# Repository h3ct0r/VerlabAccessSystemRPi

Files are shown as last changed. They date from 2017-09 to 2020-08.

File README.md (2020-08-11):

# VeRLab Access System - RPi/RFID/Face Recognition

(https://www.verlab.dcc.ufmg.br)

This is the main repo of the Verlab Access System using a Raspberry Pi as main hardware. The authentication is based on RFID or by Face Recognition (beta). List of valid users is updated from an LDAP server and maintained on the device for offline verification.

### Authors
----
- [Hector Azpurua](https://github.com/h3ct0r)
- [Elerson Rubens](https://github.com/elerson)
- [Mauricio Ferrari](https://github.com/mauferrari)

### Why using Rpi instead of Arduino?
----

We love arduino too, but our previous project using Arduino and using the compatible hardware we were able to find in Brazil ended up beign not very reliable. It seems that the ethernet shield is not the most robust piece of hardware out there, and it was a key part for that project.

Using the full power of a Raspberry Pi, it allow us to develop other methods of authentication and/or implement sound, screens, logging and other kind of funcionalities without the 16Kb space limitation. And since all Raspi-berrys are made from the same vendor and quality, we can be certain of the hardware reliability.

### Hardware Information
----
[**Hardware folder**](/hardware) has more information about 3D Printer files, connections, and assembly. 

#### Components List

This access system needs the following parts to work properly:

* *Raspberry Pi* - version 2 or up (We tested Pi2b and 3).
* *RFID Reader* - use the best RFID readers available, we use the **red ones from Funduino** (available fromm MercadoLivre.com.br sellers, look specifically the red ones). The [PN532](https://www.filipeflop.com/produto/kit-modulo-leitor-rfid-nfc-pn532/) is an excellent choice.
* *Door lock* - we used one from HDL ([FEC-91 LA](http://www.hdl.com.br/produtos/fechaduras/fecho-eletrico/fecho-eletrico-mod-fec-91-la-espelho-longo-trinco-ajustavel)).
* *Door lock Power Supply* - we used the HDL's power supply compatible with our door lock ([TRA-400](https://www.hdl.com.br/produtos/fechaduras/acessorios/fonte-tra-400-para-fechaduras-porteiros-e-centrais))
* *Relay switch* - We used common arduino relays.
* *Jumper cables* - a lot of them.
* *Two Patch Painel Female RJ45 Femal* - to leave the pinout to connect the RFID reader and Raspberry pins
* *Ethernet Cable* -  arbitrary size, to connect the RPi to the RFID reader
* Probably, will be necessary other parts for your building infrastructure that are not listed here (e.g. wall mounted plug for power, networking, electric cables, etc)

### Software Installation
----

We rely on Ansible for software installation on the Raspberry. Ansible is a 'automation' tool for configuring servers that we use to simplify the installation process on the door (for a simple guide for Ansible see [Simple Ansible Tutorial](https://serversforhackers.com/c/an-ansible-tutorial)). With this tool is very easy to deploy one or more installations of the Door System at the same time!

The installation begins on the raspberry Pi, first installing the image and then getting the right information for Ansible later make a remote installation.

##### On the Raspberry Pi

- Download the *img* file for **Raspbian LITE** and install it on an SD card [Raspbian downloads](https://www.raspberrypi.org/downloads/raspbian/).
- Connect a network cable on the Raspberry pi.
- Perform the *Hardware Installation* (of the previous section).
- Boot the SD card and activate SSH using the [raspi-config utility](https://www.raspberrypi.org/documentation/configuration/raspi-config.md).
- Change the default password for the *pi* user of this device (also possible using [raspi-config utility](https://www.raspberrypi.org/documentation/configuration/raspi-config.md)).
- Take note of the **hostname and password** you set to this device. *We will need them later*.

After the Raspberry Pi is prepared the next step is performed on the end user machine. **This GitHub repo is downloaded on the user machine and NOT on the Raspberry directly.**

##### On the user machine
- Install local dependencies to begin installation:

    `sudo apt install git ansible sshpass`

- Then clone this repository:

    `cd ~/`
    
    `git clone https://github.com/h3ct0r/VerlabAccessSystemRPi`
    
    `cd ~/VerlabAccessSystemRPi`

- Prepare Ansible and define the hosts where we will connect and perform the install:
    
    `nano ansible_install/playbooks/hosts`
    
    *Edit the fields **HOST_IP_ADDRESS** and **APPLIANCE_PASSWORD***

- Edit the configurations for the system on the *config.json* file:
    
    `nano system/config/config.json.rename`
    
    You must set at least **ldap_uri**, **ldap_username**, **ldap_passwd** and **ldap_basedn**.

- Then run the installation:
    
    `cd ansible_install/playbooks/`
    
    `ansible-playbook -s -v full_raspi_config.yaml`

##### Finalizing installation

- Enter the device machine via SSH:
    
    `ssh pi@HOST_IP_ADDRESS`
    
- Open the syslog file:

    `sudo tail -f /var/log/syslog`
    
- Test if there are I2C devices connected:

    `sudo i2cdetect -y 1`
    
- Use a RFID card and test it on the device. If all went OK you will see DEBUG information on the log.

This installation was lousy based on [How to Rpi RFID](https://www.sunfounder.com/wiki/index.php?title=How_to_Use_an_RFID_RC522_on_Raspberry_Pi) and [Rpi services](http://blog.scphillips.com/posts/2013/07/getting-a-python-script-to-run-in-the-background-as-a-service-on-boot/).

### Manage services
---

The system is based on daemons, to restart a service the commands are:
- `sudo /etc/init.d/relay_server.sh restart`
- `sudo /etc/init.d/rfid_server.sh restart`

All services log to *syslog* so to verify installation or real time operation just need to:
- `sudo tail -f /var/log/syslog`

### Todos
----

 - RFID robust search.
 - Face detection (?).
 - Web config interface.
 - Write moar tests.

License
----

Custom license, please see [Our license agreement](https://github.com/h3ct0r/VerlabAccessSystemRPi/blob/master/LICENSE) first before using this software.

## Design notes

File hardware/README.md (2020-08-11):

# [VeRLab Access System](https://github.com/h3ct0r/VerlabAccessSystemRPi/)
(https://www.verlab.dcc.ufmg.br)

# Hardware Information

## RPi Connections
---
RFID reader PCB pins:

|Signal Name|J8 Pin#|RPi Pin Name|
|---|---|---|
|VCC|17|3V3|
|RST|22|GPIO25|
|GND|20|Ground|
|MISO|21|GPIO9|
|MOSI|19|GPIO10|
|SCK|23|GPIO11|
|SDA|24|GPIO8|
|IRQ|None|Not Connected|

Relay PCB pins:

|Signal Name|J8 Pin#|RPi Pin Name|
|---|---|---|
|VCC|4|5V|
|GND|6|Ground|
|Relay_on|7|GPIO4|

## Casing files
---
The casing has two parts: cover and case. There are some different file extensions:

- *.stl: 3D model files, that could be loaded in a slicer software and used to print your casing with a 3D printer.

- *.pdf: some dimensions of the casing  parts

- *.png: just images to visualize the casing parts. They are screeshots of the *.stl files loaded in the 
[ideaMaker Software](https://www.raise3d.com/ideamaker/)

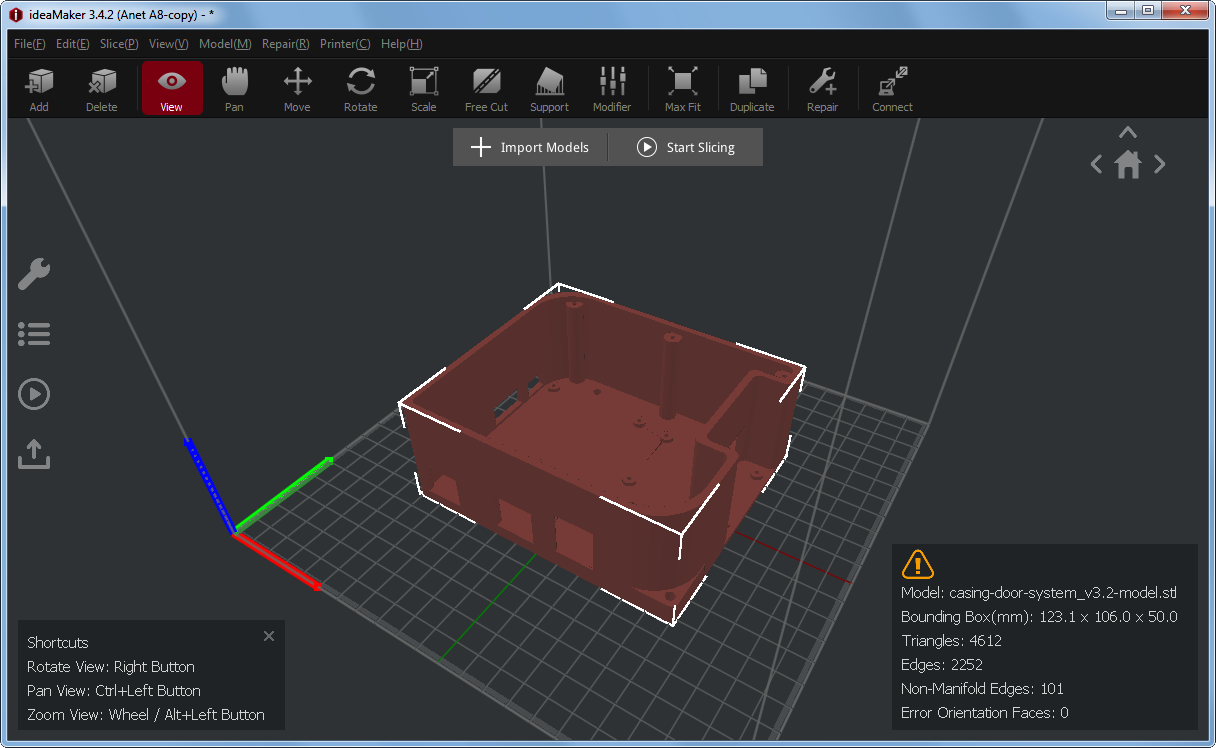
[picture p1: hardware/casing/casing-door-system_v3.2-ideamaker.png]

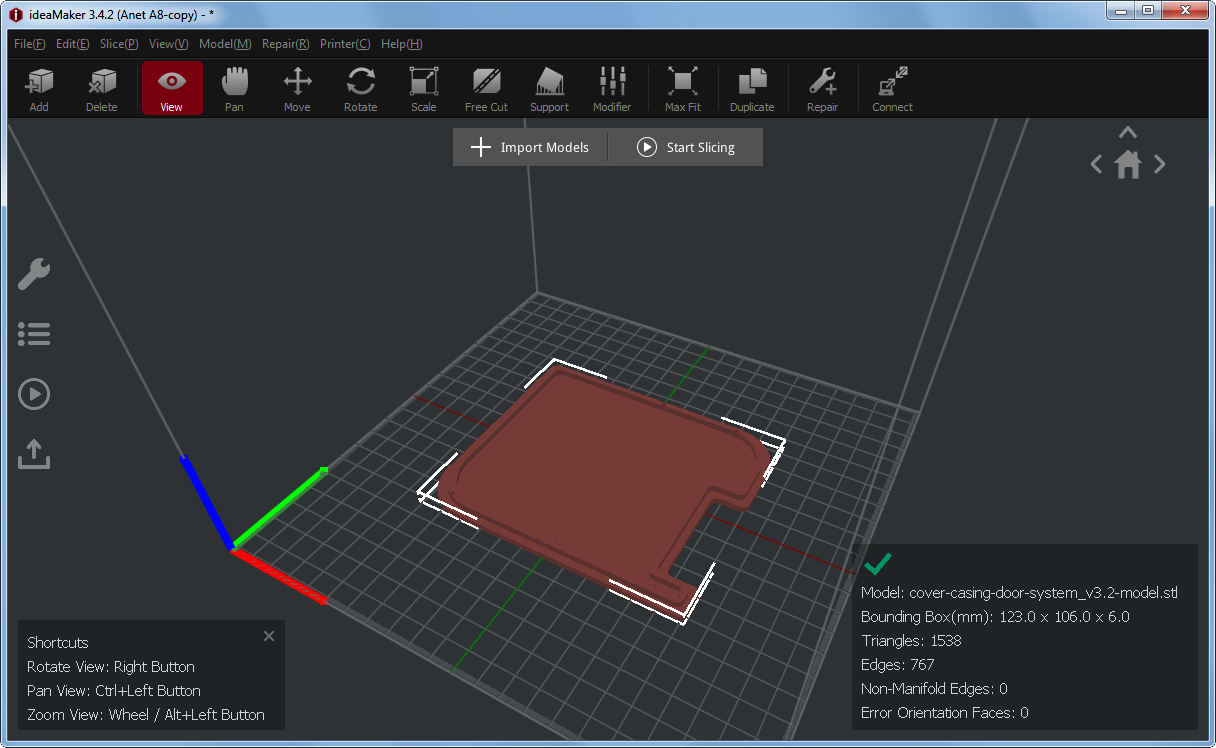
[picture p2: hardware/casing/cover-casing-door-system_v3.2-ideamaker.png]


## Assembly example
---
- Casing and parts mounted in a place inside the room. Its
  necessary a wall-mounted power plug, and a network access plug to control the system remotely.

PS: The system casing is important to be in a safe place, just for authorized persons, because there are security data saved inside the SD Card.

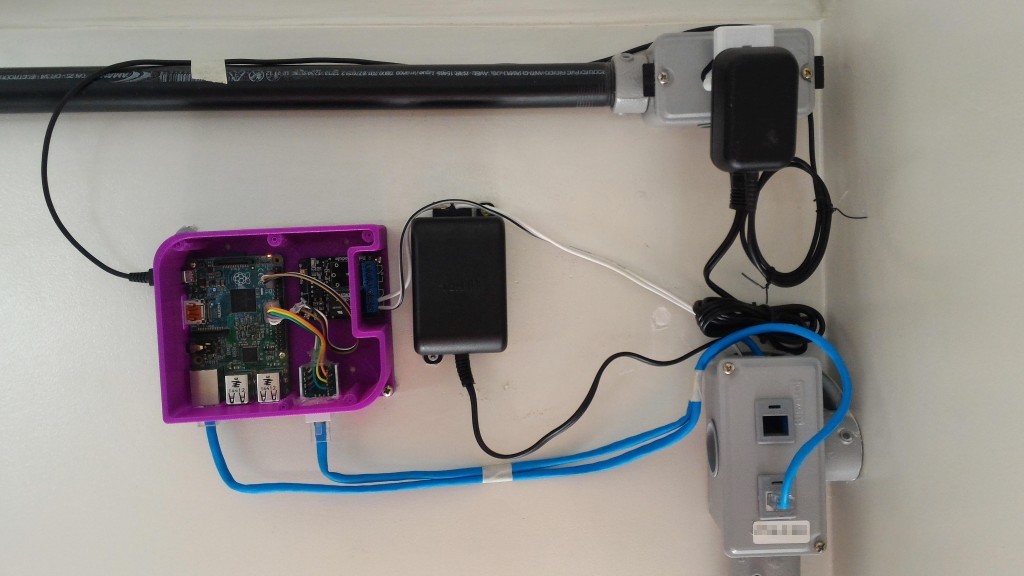
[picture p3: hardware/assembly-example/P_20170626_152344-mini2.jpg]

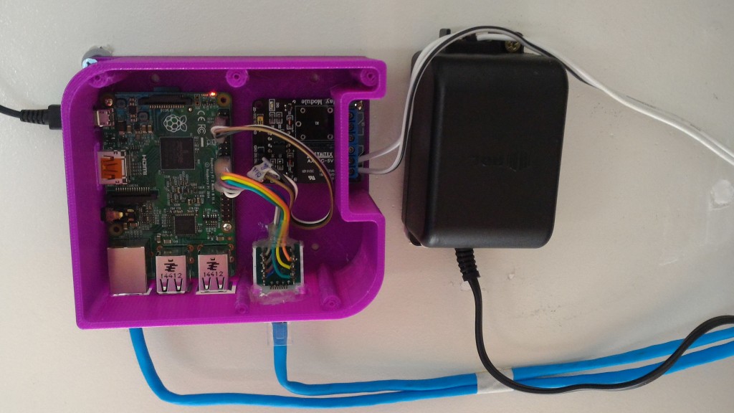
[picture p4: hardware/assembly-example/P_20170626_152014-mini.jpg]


- An Ethernet cable and RJ45 panel connectors were used to connect the RFID reader from the wall outside the room to the System casing. in our practical experience, it was the best solution to make the connection of the 7 SPI signals in a robust way and avoiding bad contact. 

Note: This ethernet cable is just a medium for the signals, it doesn't transmit network ethernet data!

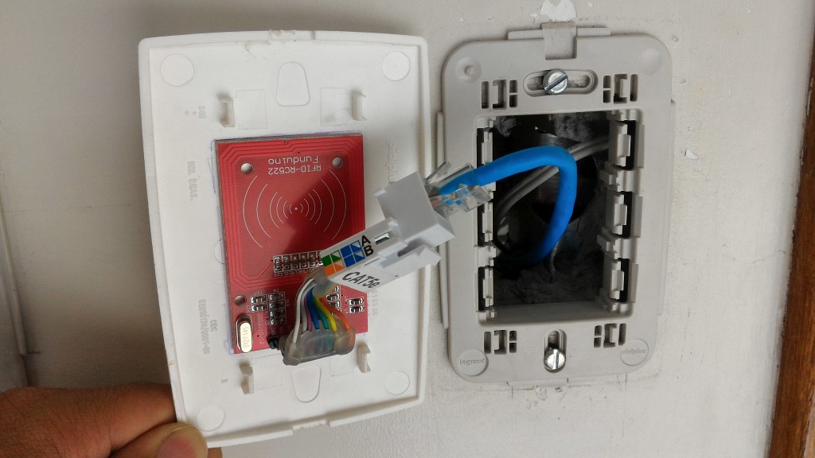
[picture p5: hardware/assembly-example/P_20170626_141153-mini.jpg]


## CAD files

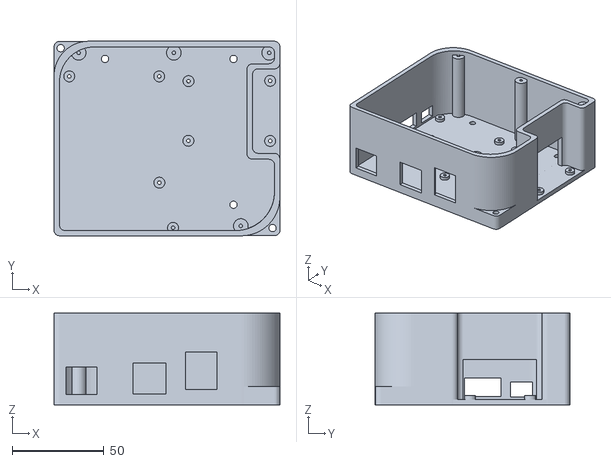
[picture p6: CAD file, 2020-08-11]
hardware/casing/casing-door-system_v3.2-model.stl
123.1 x 106.0 x 50.0

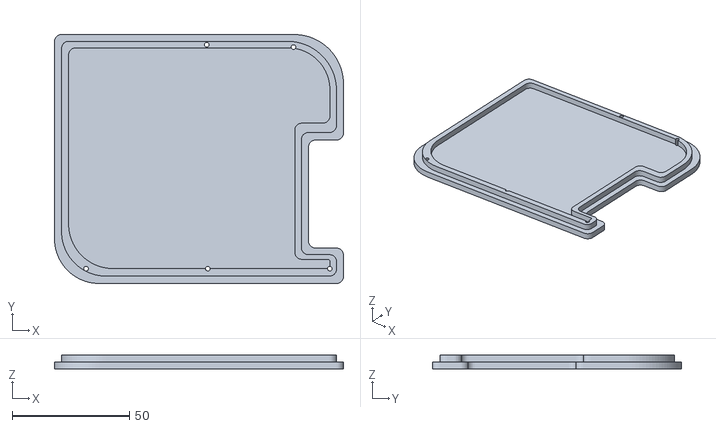
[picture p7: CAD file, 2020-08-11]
hardware/casing/cover-casing-door-system_v3.2-model.stl
123.0 x 106.0 x 6.00

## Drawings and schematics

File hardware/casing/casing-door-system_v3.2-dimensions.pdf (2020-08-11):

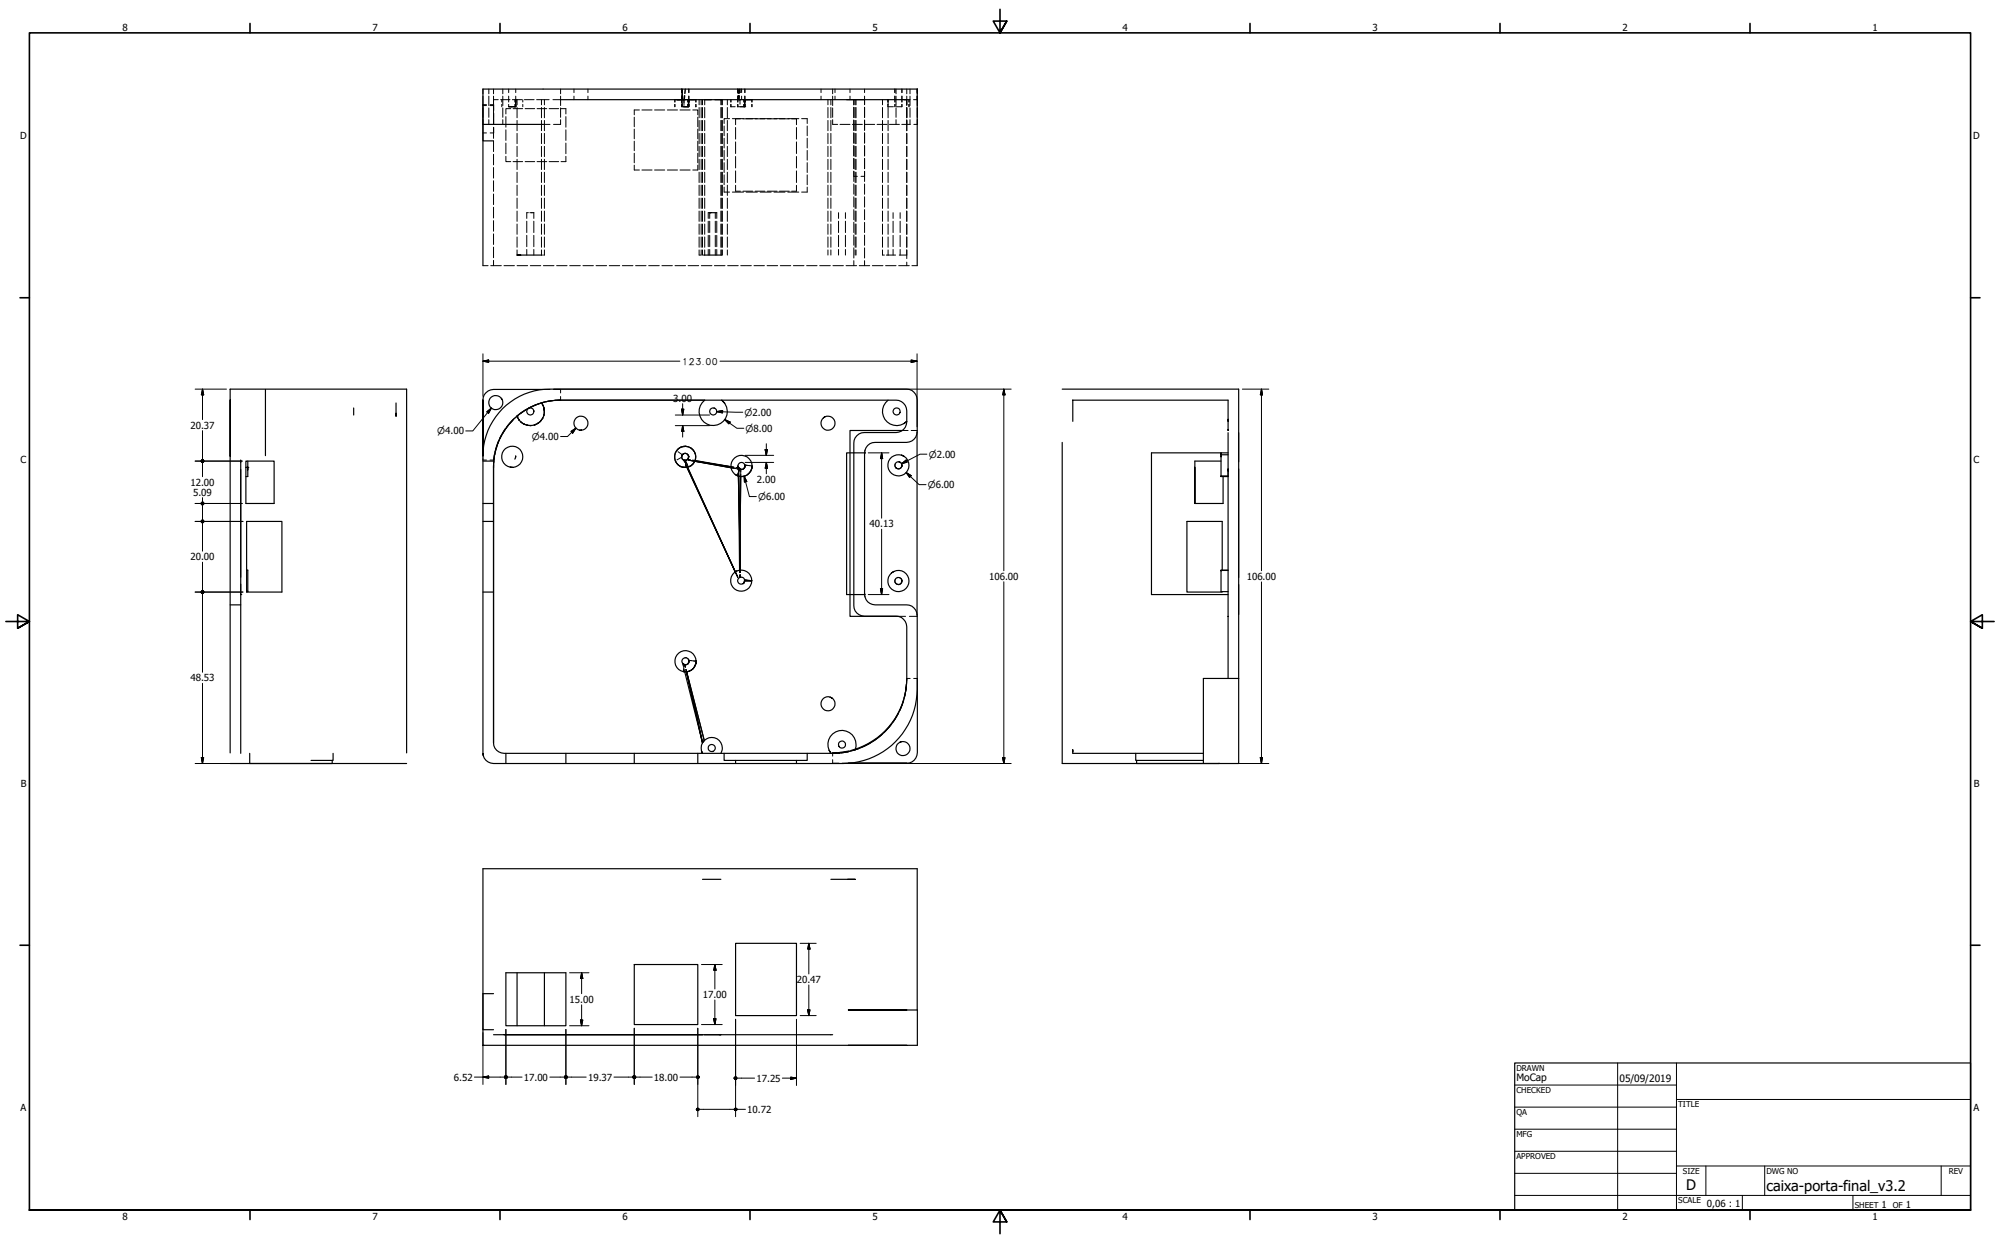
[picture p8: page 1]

DRAWN MoCap | 05/09/2019

CHECKED

MFG

APPROVED

SIZE D | DWG NO caixa-porta-final_v3.2 | REV

SCALE 0,06 : 1 | | SHEET 1 OF 1

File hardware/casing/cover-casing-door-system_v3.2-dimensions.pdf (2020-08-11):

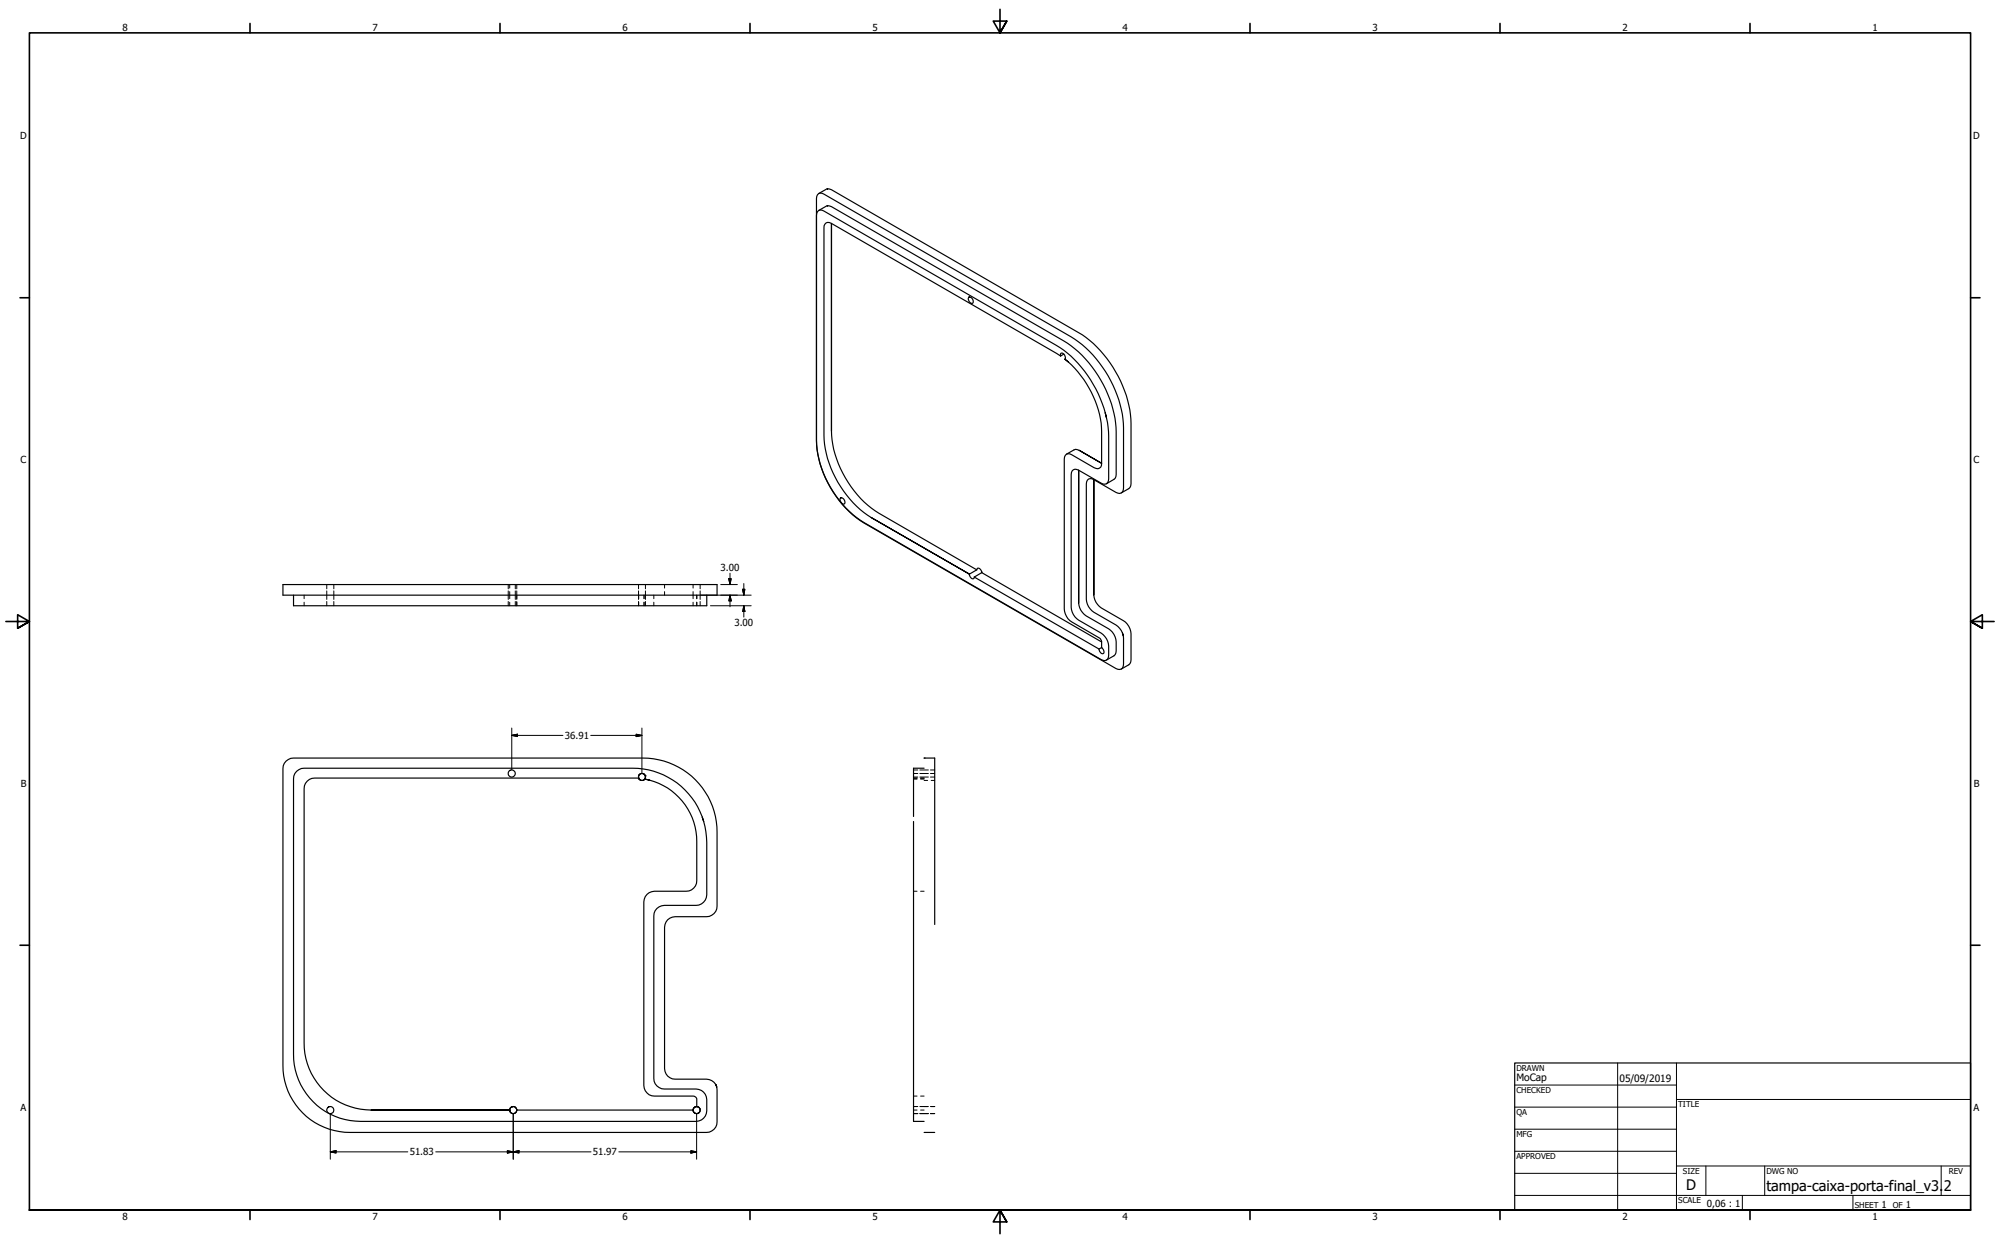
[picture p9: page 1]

DRAWN MoCap | 05/09/2019

CHECKED

MFG

APPROVED

SIZE D | DWG NO tampa-caixa-porta-final_v3.2 | REV

SCALE 0,06 : 1 | | SHEET 1 OF 1

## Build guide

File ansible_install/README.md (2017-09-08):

# Ansible install procedures

Refer to the main page to install procedures [Main project page](https://github.com/h3ct0r/VerlabAccessSystemRPi).

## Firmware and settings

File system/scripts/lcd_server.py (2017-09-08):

#!/usr/bin/env python

from multiprocessing.connection import Listener
from threading import Thread
from Queue import Queue
import json
import time
import sys
import smbus
import socket
import fcntl
import struct
import logging
import logging.handlers
import subprocess


class LCDControl:

    def __init__(self, i2c_address=0x3f, is_backlight_on=True):
        self.i2c_address = i2c_address
        self.lcd_width = 16
        self.lcd_chr = 1
        self.lcd_cmd = 0
        self.lcd_line_1 = 0x80
        self.lcd_line_2 = 0xC0
        self.lcd_line_3 = 0x94
        self.lcd_line_4 = 0xD4

        self.lcd_backlight = 0x00
        if is_backlight_on:
            self.lcd_backlight = 0x08

        self.enable_bit = 0b00000100
        self.e_pulse = 0.0005
        self.e_delay = 0.0005

        # Rev 1 Pi uses 0, Rev 2 uses 1
        self.bus = smbus.SMBus(1)
        self.init()
        pass

    def init(self):
        self.send_byte(0x33, self.lcd_cmd)  # 110011 Initialise
        self.send_byte(0x32, self.lcd_cmd)  # 110010 Initialise
        self.send_byte(0x06, self.lcd_cmd)  # 000110 Cursor move direction
        self.send_byte(0x0C, self.lcd_cmd)  # 001100 Display On,Cursor Off, Blink Off
        self.send_byte(0x28, self.lcd_cmd)  # 101000 Data length, number of lines, font size
        self.send_byte(0x01, self.lcd_cmd)  # 000001 Clear display
        time.sleep(self.e_delay)

    def send_byte(self, bits, mode):
        # Send byte to data pins
        # bits = the data
        # mode = 1 for data
        #        0 for command

        bits_high = mode | (bits & 0xF0) | self.lcd_backlight
        bits_low = mode | ((bits << 4) & 0xF0) | self.lcd_backlight

        # High bits
        self.bus.write_byte(self.i2c_address, bits_high)
        self.toggle_enable(bits_high)

        # Low bits
        self.bus.write_byte(self.i2c_address, bits_low)
        self.toggle_enable(bits_low)

    def toggle_enable(self, bits):
        # Toggle enable
        time.sleep(self.e_delay)
        self.bus.write_byte(self.i2c_address, (bits | self.enable_bit))
        time.sleep(self.e_pulse)
        self.bus.write_byte(self.i2c_address, (bits & ~self.enable_bit))
        time.sleep(self.e_delay)

    def send_string(self, message, line):
        # Send string to display
        message = message.ljust(self.lcd_width, " ")
        self.send_byte(line, self.lcd_cmd)
        for i in range(self.lcd_width):
            self.send_byte(ord(message[i]), self.lcd_chr)

    def send_string_list(self, msg):
        if len(msg) != 2:
            return

        l1 = msg[0]
        self.send_string(l1, self.lcd_line_1)

        l2 = msg[1]
        self.send_string(l2, self.lcd_line_2)


def get_ip_address(ifname):
    p = subprocess.Popen("ifconfig {} | grep 'inet addr' | cut -d ':' -f 2 | cut -d ' ' -f 1".format(ifname), stdout=subprocess.PIPE, stderr=subprocess.PIPE, shell=True)
    out, err = p.communicate()
    return out.strip()
    
def reset_screen(logger, lcd, queue):
	last_update = 0
	is_dirty = True
	q_time = None
	
	while(True):
		try:
			q_time = queue.get_nowait()
			if q_time is not None:
				last_update = q_time
				is_dirty = True
		except Exception, e:
			q_time = None
		
		ctime = float(time.time())
		timediff = abs(ctime - last_update)
		
		if is_dirty and timediff > 5:
			logger.debug('Resetting screen isdirty:{}, ctime{}, timediff:{}'.format(is_dirty, ctime, timediff))
			is_dirty = False
			lcd.send_string_list(["**** VeRLab ****", "Vision& Robotics"])
			
		time.sleep(1)
		pass
	pass

def main(cfg):
    logger = logging.getLogger('RFID_SRV')
    logger.setLevel(logging.DEBUG)
    handler = logging.handlers.SysLogHandler(address = '/dev/log')
    formatter = logging.Formatter('%(name)s - %(levelname)s - %(message)s')
    handler.setFormatter(formatter)
    logger.addHandler(handler)
    
    logger.debug('Starting lcd control...')
    lcd = LCDControl()
    address = ('localhost', cfg['lcd_port'])
    keep_running = True
    logger.debug('Sending init LCD...')
    ip_addr= get_ip_address('eth0')
    logger.debug('IP: {}'.format(ip_addr))
    lcd.send_string_list(["Init LCD server", ip_addr])
    
    # Start reset thread
    queue = Queue()
    queue.put(int(time.time()))
    t1 = Thread(target=reset_screen, args=(logger, lcd, queue,))
    t1.setDaemon(True)
    t1.start()
    
    logger.info('LCD server started and waiting for connections')
    
    while keep_running:
        listener = Listener(address, authkey=cfg['process_passwd'].encode())
        conn = listener.accept()
        logger.debug('connection accepted from {}'.format(listener.last_accepted))

        try:
            while True:
                if conn.poll():
                    msg = conn.recv()
                    logger.debug('Received: {}'.format(msg))

                    if not isinstance(msg, list):
                        if msg == 'shutdown':
                            conn.close()
                            keep_running = False
                            listener.close()
                            break
                        else:
                            logger.debug('Not a list or shutdown msg')
                            break

                    queue.put(float(time.time()))

                    lcd.send_string_list(msg)
        except Exception as e:
            if str(e) != "":
                logger.error(e)
            listener.close()

    listener.close()
    lcd.send_byte(0x01, lcd.lcd_cmd)
    pass

if __name__ == "__main__":
    with open('/var/doorsystem/config/config.json') as data_file:
        config = json.load(data_file)

    main(config)

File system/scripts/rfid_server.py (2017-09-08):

#!/usr/bin/env python

from multiprocessing.connection import Client
import json
import time
import sys
import RPi.GPIO as GPIO
from MFRC522 import MFRC522
import os
import socket
from threading import Thread
import logging
import logging.handlers


def check_uid_access(uid):
    data_path = '/var/doorsystem/data/data.json'

    if not os.path.isfile(data_path):
        print '[RFID_SERVER]', 'Cannot find RFID data'
        return None

    with open(data_path) as data_file:
        data = json.load(data_file)

    for k,v in data.items():
        if v['accessToken'] == str(uid):
            return v

    return None

def send_socket_msg(address, key, msg):
    try:
        conn_lcd = Client(address, authkey=key)
        conn_lcd.send(msg)
        conn_lcd.close()
    except Exception as e:
        print '[ERROR]', e
    pass

def main(cfg):
    logger = logging.getLogger('RFID_SRV')
    logger.setLevel(logging.DEBUG)
    handler = logging.handlers.SysLogHandler(address = '/dev/log')
    formatter = logging.Formatter('%(name)s - %(levelname)s - %(message)s')
    handler.setFormatter(formatter)
    logger.addHandler(handler)
    
    rfid = MFRC522.MFRC522()

    address_relay = ('localhost', cfg['relay_port'])
    address_lcd = ('localhost', cfg['lcd_port'])
    keep_running = True
    
    logger.info('RFID server started and waiting for RFID tags')

    while keep_running:
        # Scan for cards
        (status, tag_type) = rfid.MFRC522_Request(rfid.PICC_REQIDL)

        # If a card is found get UID
        if status == rfid.MI_OK:
            (status, uid) = rfid.MFRC522_Anticoll()

        # If we have the UID, continue
        if status == rfid.MI_OK:
            # Prepare UID, delete last bit (inconsistency with previous readings??)
            if len(uid) > 2:
                uid.pop()

            hex_uid = ''.join(format(x, 'x') for x in uid)
            logger.debug('UID: {} {}'.format(uid, hex_uid))

            check_res = check_uid_access(hex_uid)
            if check_res is not None:
                logger.info('Access granted')
                try:
                    t1 = Thread(target=send_socket_msg, args=(address_relay, cfg['process_passwd'].encode(), 'open_door'))
                    t1.setDaemon(True)
                    t1.start()
                    
                    #t2 = Thread(target=send_socket_msg, args=(address_lcd, cfg['process_passwd'].encode(), ["Welcome:", check_res["givenName"]]))
                    #t2.setDaemon(True)
                    #t2.start()
                except Exception as e:
                    if str(e) != "":
                        logger.debug(e)
                # TODO: Play access granted
            else:
                logger.debug('Access denied')
                #t1 = Thread(target=send_socket_msg, args=(address_lcd, cfg['process_passwd'].encode(), [" --- ALERT --- ", " ACCESS DENIED "]))
                #t1.setDaemon(True)
                #t1.start()
                # TODO: Play access denied
                pass
            
            time.sleep(1)
        else:
            time.sleep(0.2)           

    GPIO.cleanup()
    pass


if __name__ == "__main__":
    with open('/var/doorsystem/config/config.json') as data_file:
        config = json.load(data_file)

    main(config)

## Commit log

2016-12-20 Testing timeout in relay server
2016-12-21 Added rfid server, fixed several bugs, added lcd server
    [rfid_server.py]
2017-02-23 Fixed minor bugs and added daemon scripts
    [lcd_server.py, relay_server.py, rfid_server.py]
2017-03-07 updated daemons and added timer to lcd server to init (fix this on future)
    [lcd_server.py]
2017-03-07 added message to fix timer
    [lcd_server.py]
2017-03-13 added logging support and removed timers in lcd
2018-03-20 Update README.md
    added information about relay connection
2020-08-08 Add hadware folder and files
    - casing: files to 3D printing
    - assembly: images of an assembly example
    [casing-door-system_v3.2-model.stl, cover-casing-door-system_v3.2-model.stl]
